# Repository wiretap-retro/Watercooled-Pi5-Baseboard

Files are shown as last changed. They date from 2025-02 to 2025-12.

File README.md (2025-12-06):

# Watercooled Pi5 Baseboard
A baseboard for setting up a watercooled Raspberry Pi 5.

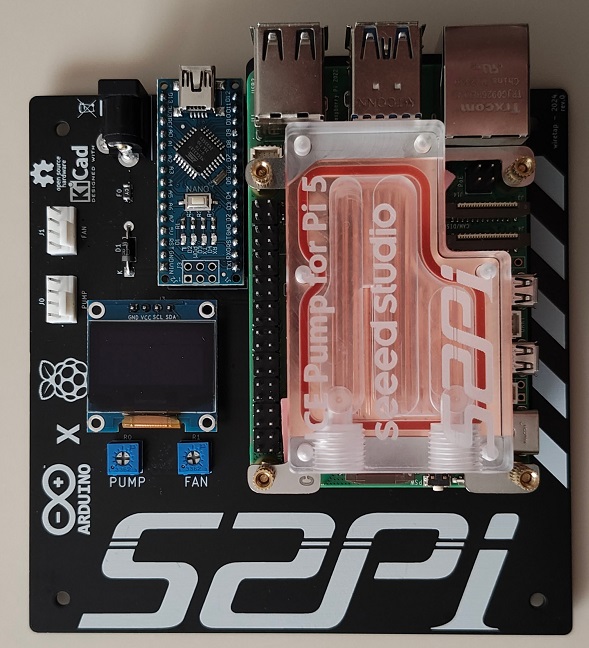
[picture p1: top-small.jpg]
board

\
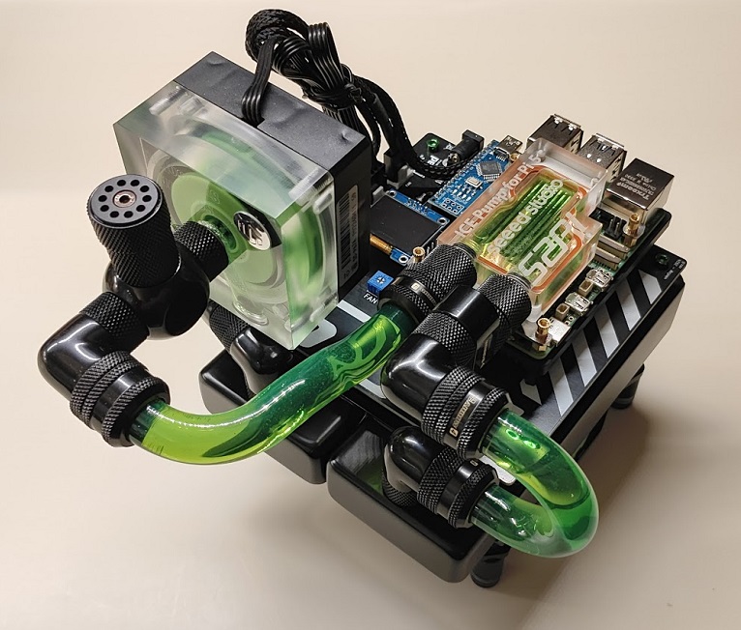
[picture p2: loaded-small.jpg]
board2

\
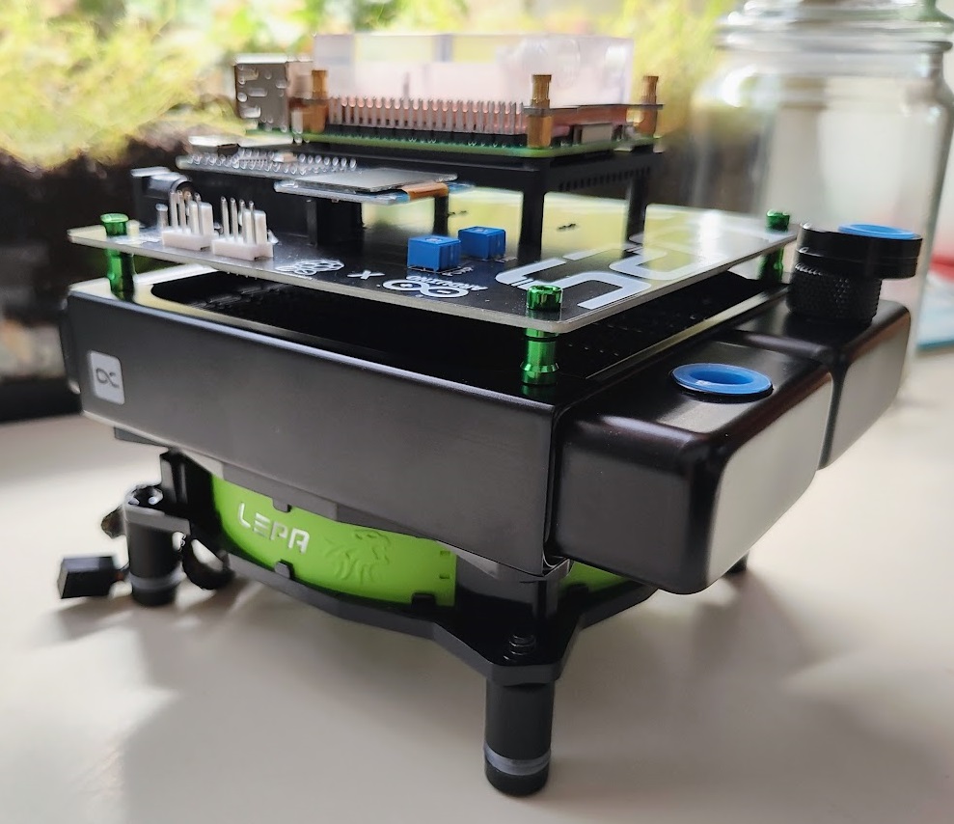
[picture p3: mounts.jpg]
mounts


## Info
In this repository you'll find my Watercooled Raspberry Pi 5 baseboard. It features mounts for the Raspberry Pi 2/3/4/5, an Arduino Nano, and a 120mm fan/radiator. The baseboard is powered through the 5.5x2.1mm 12V barrel jack, which powers the pump, fan, and Arduino. There is an onboard 4A fuse for protection. The Pi is powered separate with its own USB power input.\
\
The Arduino is used for the PWM fan and pump control so it leaves the entire Pi header available for hat use. \
\
Arduino Nano connections:\
A0: Pump Adjustment 10k trim pot input \
A1: Fan Adjustment 10k trim pot input \
A4: SDA for OLED screen (SSD1306 model) \
A5: SCL for OLED screen (SSD1306 model) \
D2: Pump tachometer input \
D6: Fan tachometer input \
D9: PWM pump demand output \
D10: PWM fan demand output
\
\
For the radiator and fan, you'll want to use some generic standoffs commonly found on Aliexpress, Amazon, or Ebay. These will all depend on your fan and radiator choices for what fits best. A M3 5mm standoff provides a sufficient gap between the board and radiator to allow airflow to pass through. After all, watercooling even a Raspberry Pi 5 is pointless and passive cooling alone is enough at the factory clockspeed. 

## Code
I have uploaded some sample code for you. When designing the board, I stupidly designed the tach pins where only one of the ports has an interrupt capability. This requires using the PinChangeInterrupts library. I have attached the settings file for you to overwrite the one that is automatically downloaded, then it will properly display the fan tachometer. This code is fully tested working for fan and pump control.
\
See picture below for the screen layout:
\
\
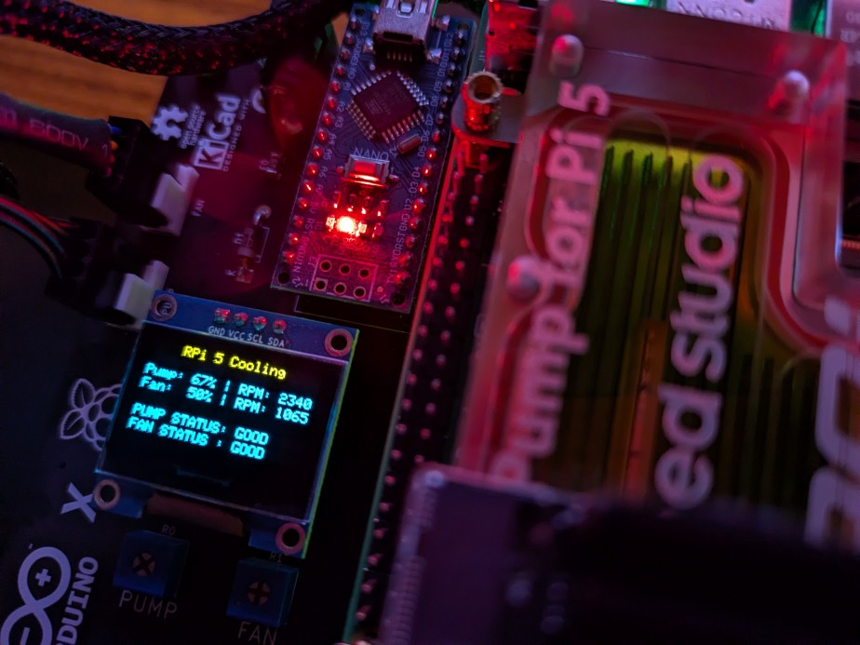
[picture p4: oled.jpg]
oled

## License
UNLICENSE -- do what you want with it.

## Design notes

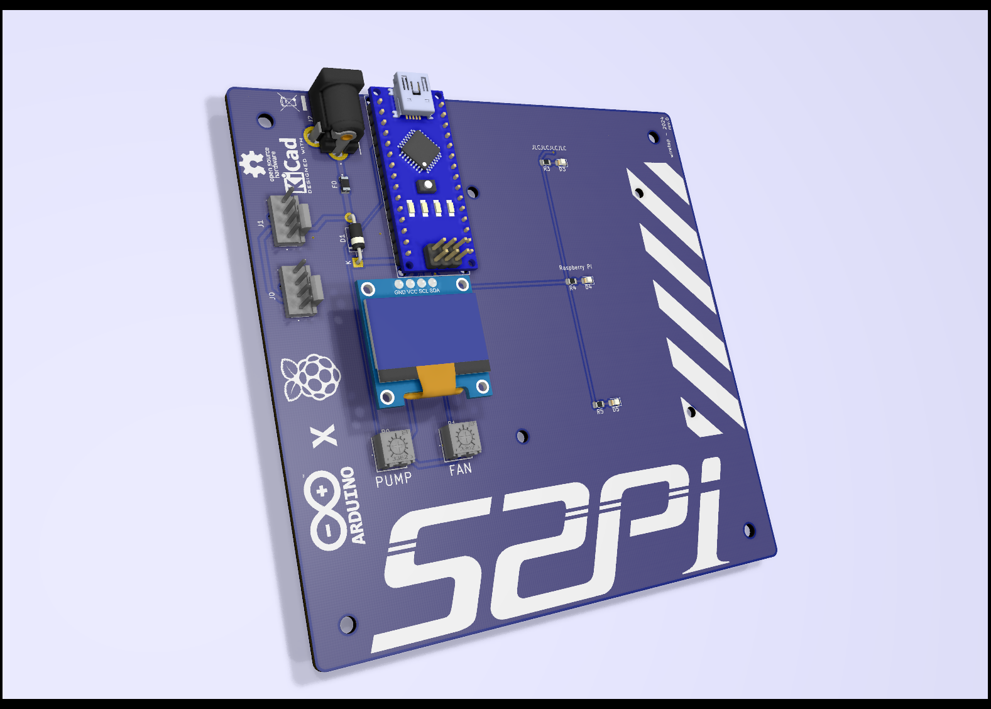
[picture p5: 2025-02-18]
Pi5-wc-board/watercooled-pi-120mm.png

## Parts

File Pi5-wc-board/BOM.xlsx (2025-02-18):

Reference | Quantity | Value | Footprint | Manufacturer | Part Number | Mouser Part Number | Notes
D1 | 1 | 1N4007 | Diode_THT:D_DO-41_SOD81_P10.16mm_Horizontal | Diotec Semiconductor | 1N4007 | 637-1N4007
D2 D3 D4 D5 D6 D7 D8 D9 D10 D11 D12 D13 | 12 | LED_Small | LED_SMD:LED_0805_2012Metric_Pad1.15x1.40mm_HandSolder |  |  |  | Any 0805 SMD LED
F0 | 1 | 1206L400_12SLWR | 1206L075SLYR | LITTELFUSE | 1206L400/12SLWR | 576-1206L400/12SLWR
J1 J0 | 2 | 47053-3000 | 470533000 | Molex | 47053-3000 | 538-47053-3000
J2 | 1 | 694106301002 | 694106301002_1 | Wurth Elektronik | 694106301002 | 710-694106301002
J3 | 1 | Conn_01x04 | Connector_PinSocket_2.54mm:PinSocket_1x04_P2.54mm_Vertical | Harwin | M20-7820446 | 855-M20-7820446
R1 R0 | 2 | 3362P-1-103 | 3362P_1 | Bourns | 3362P-1-103 | 652-3362P-1-103
R2 R3 R4 R5 R6 R7 R8 R9 R10 R11 R12 R13 | 12 | R_Small | Resistor_SMD:R_0805_2012Metric_Pad1.15x1.40mm_HandSolder |  |  |  | 0805 SMD resistor appropriate for your LEDs (i.e. 1k)
TB0 | 1 | ARDUINO_NANO | SamacSys_Parts:Arduino_Nano_Socket | Arduino | Nano |  | Arduino Nano header is optional -- can direct solder

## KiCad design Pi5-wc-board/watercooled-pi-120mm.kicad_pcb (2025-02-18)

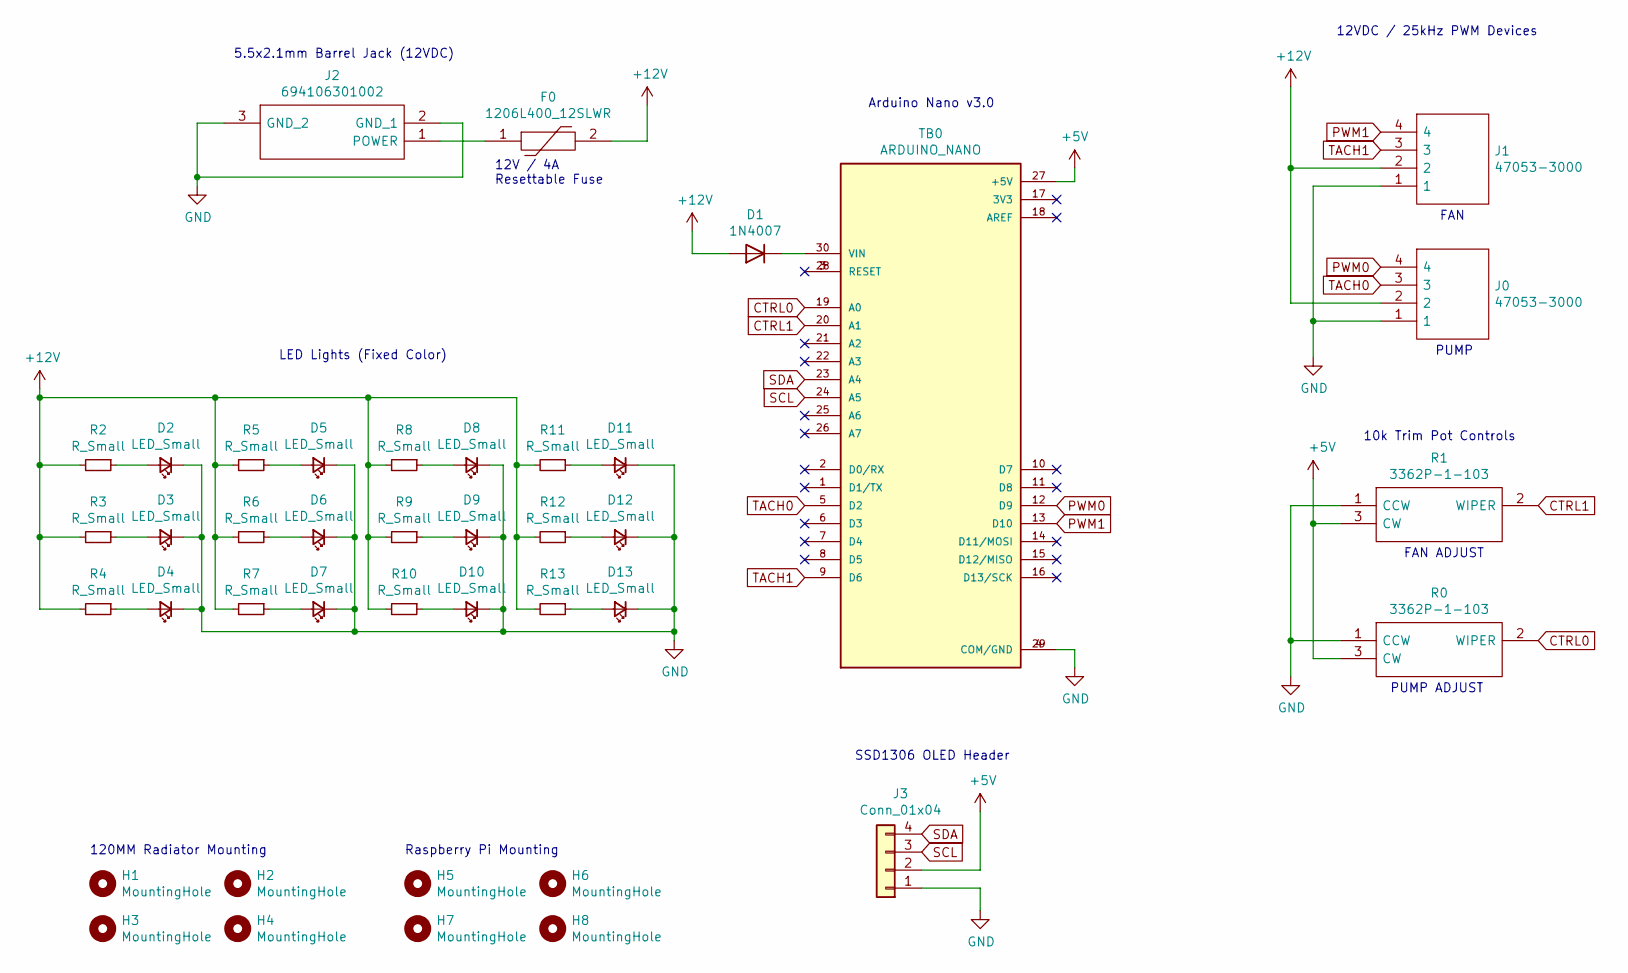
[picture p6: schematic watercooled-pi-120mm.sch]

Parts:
D1: 1N4007; D_DO-41_SOD81_P10.16mm_Horizontal
D2, D3, D4, D5, D6, D7, D8, D9, D10, D11, D12, D13: LED_Small; LED_0805_2012Metric_Pad1.15x1.40mm_HandSolder
F0: 1206L400_12SLWR; 1206L075SLYR; Mouser Part Number 576-1206L400/12SLWR
H1, H2, H3, H4: MountingHole; MountingHole_3.2mm_M3
H5, H6, H7, H8: MountingHole; MountingHole_2.7mm_M2.5
J0, J1: 47053-3000; 470533000; Mouser Part Number 538-47053-3000
J2: 694106301002; 694106301002_1; Mouser Part Number 710-694106301002
J3: Conn_01x04; PinSocket_1x04_P2.54mm_Vertical
R0, R1: 3362P-1-103; 3362P_1; Mouser Part Number 652-3362P-1-103
R2, R3, R4, R5, R6, R7, R8, R9, R10, R11, R12, R13: R_Small; R_0805_2012Metric_Pad1.15x1.40mm_HandSolder
TB0: ARDUINO_NANO; Arduino_Nano_Socket

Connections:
+5V: J3.2, R0.3 (CW), R1.3 (CW), TB0.27 (+5V)
+12V: D1.2 (A), F0.2, J0.2, J1.2, R2.2, R3.2, R4.2, R5.2, R6.2, R7.2, R8.2, R9.2, R10.2, R11.2, R12.2, R13.2
CTRL0: R0.2 (WIPER), TB0.19 (A0)
CTRL1: R1.2 (WIPER), TB0.20 (A1)
GND: D2.1 (K), D3.1 (K), D4.1 (K), D5.1 (K), D6.1 (K), D7.1 (K), D8.1 (K), D9.1 (K), D10.1 (K), D11.1 (K), D12.1 (K), D13.1 (K), J0.1, J1.1, J2.2 (GND_1), J2.3 (GND_2), J3.1, R0.1 (CCW), R1.1 (CCW), TB0.4 (COM/GND), TB0.29 (COM/GND)
unnamed: D1.1 (K), TB0.30 (VIN)
unnamed: D2.2 (A), R2.1
unnamed: D3.2 (A), R3.1
unnamed: D4.2 (A), R4.1
unnamed: D5.2 (A), R5.1
unnamed: D6.2 (A), R6.1
unnamed: D7.2 (A), R7.1
unnamed: D8.2 (A), R8.1
unnamed: D9.2 (A), R9.1
unnamed: D10.2 (A), R10.1
unnamed: D11.2 (A), R11.1
unnamed: D12.2 (A), R12.1
unnamed: D13.2 (A), R13.1
unnamed: F0.1, J2.1 (POWER)
unnamed: TB0.3 (RESET), TB0.28 (RESET)
PWM0: J0.4, TB0.12 (D9)
PWM1: J1.4, TB0.13 (D10)
SCL: J3.3, TB0.24 (A5)
SDA: J3.4, TB0.23 (A4)
TACH0: J0.3, TB0.5 (D2)
TACH1: J1.3, TB0.9 (D6)

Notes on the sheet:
FAN
PUMP
12VDC / 25kHz PWM Devices
Arduino Nano v3.0
FAN ADJUST
PUMP ADJUST
10k Trim Pot Controls
12V / 4A Resettable Fuse
5.5x2.1mm Barrel Jack (12VDC)
SSD1306 OLED Header
120MM Radiator Mounting
Raspberry Pi Mounting
LED Lights (Fixed Color)

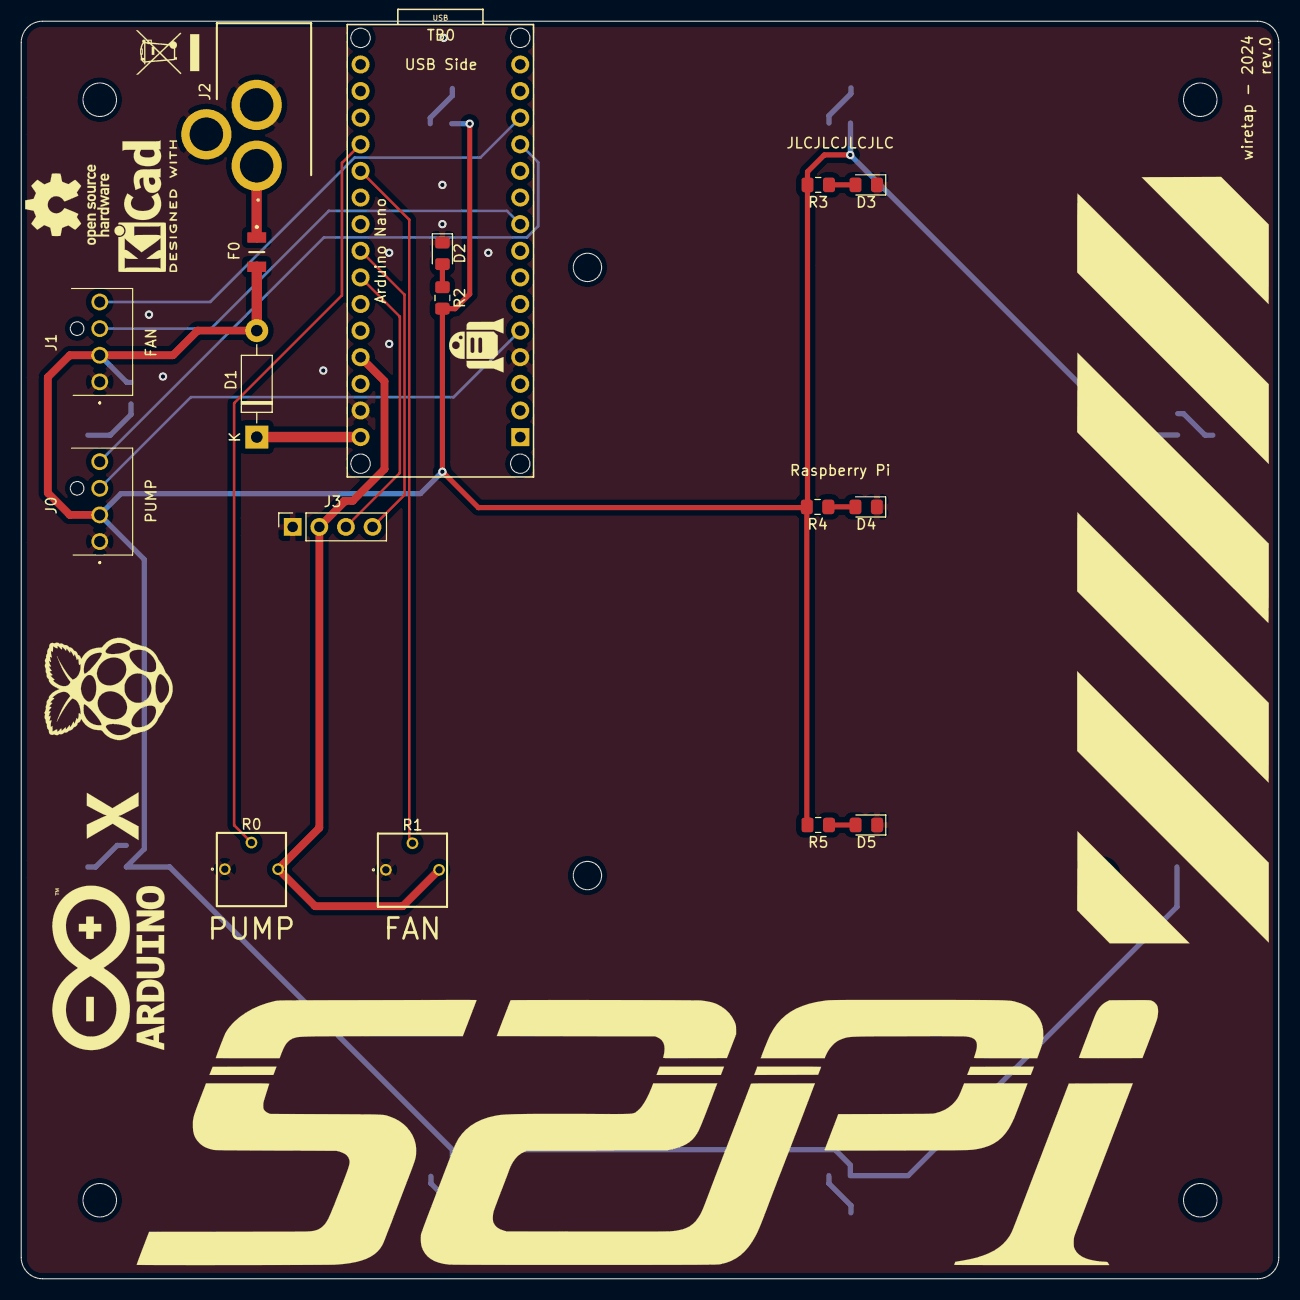
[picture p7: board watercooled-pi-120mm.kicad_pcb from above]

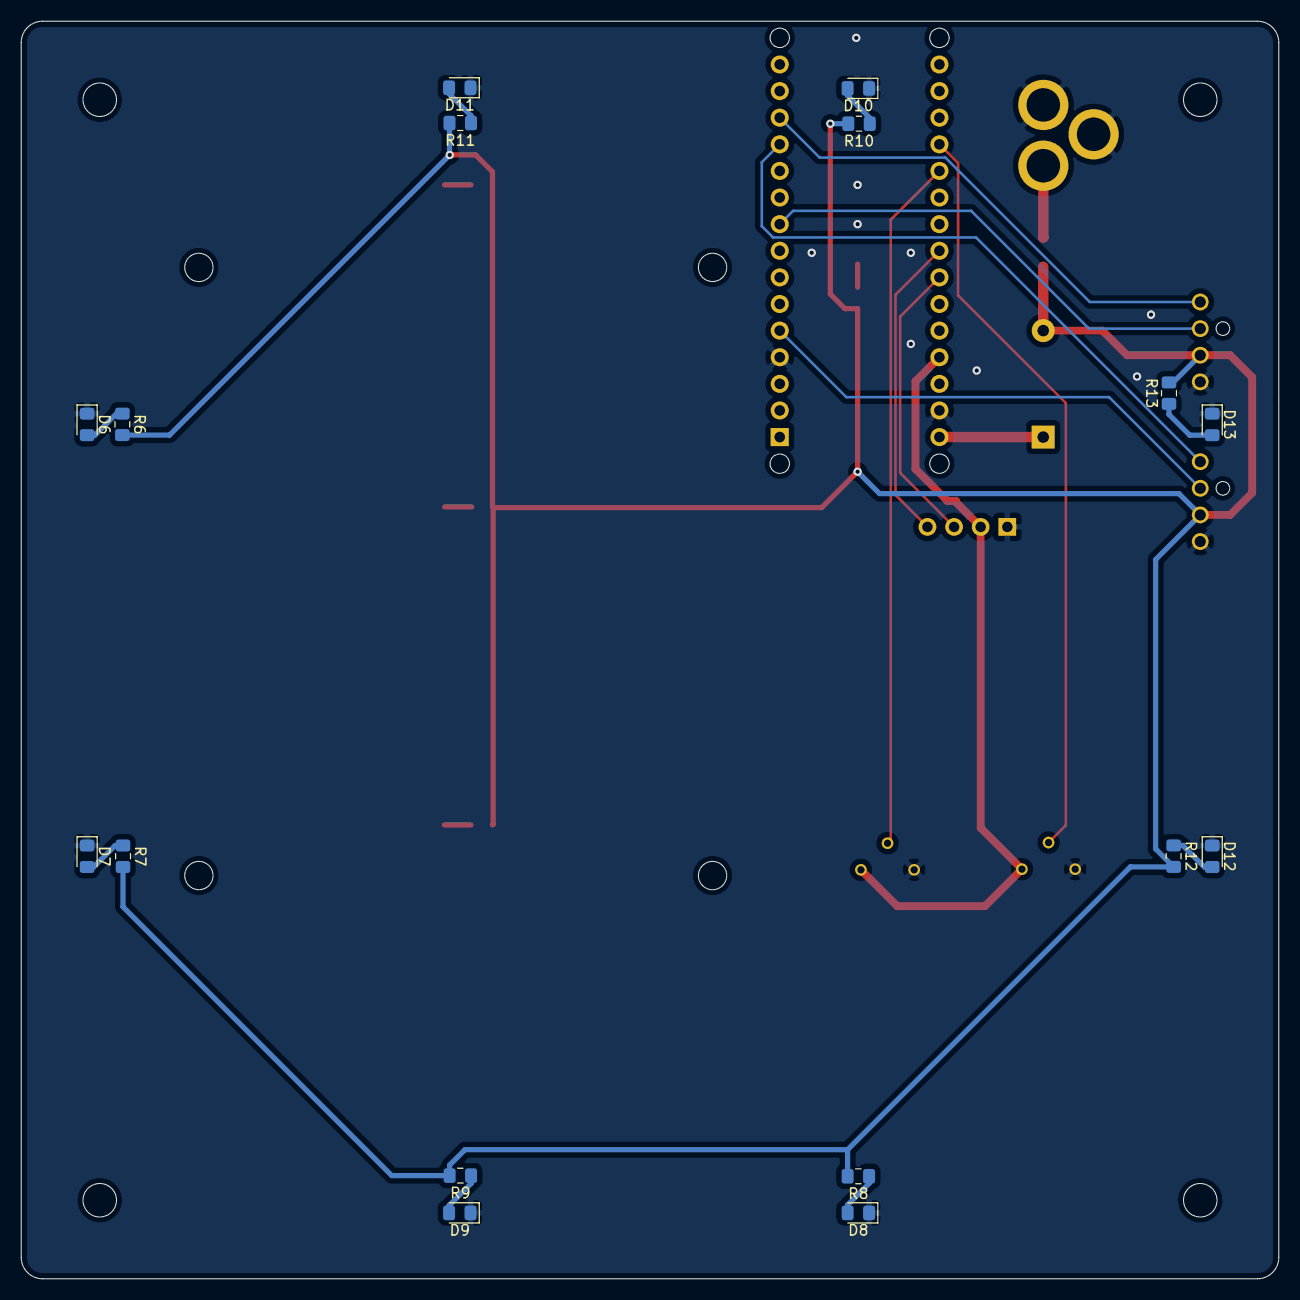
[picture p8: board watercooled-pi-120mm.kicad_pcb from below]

Board: 2 copper layers, 120.0 x 120.0 mm, 41 parts (16 on the bottom side), 26 nets.

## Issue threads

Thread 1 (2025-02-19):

0805 smd led

TheRealKingPin, 2025-02-19:
Random question, did you solder the 0805 smd leds to the top and bottom of the board? I'm assuming these are what are providing the green underglow in some of your images.

wiretap-retro, 2025-02-19:
Yes, those are just LEDs for the purpose of underglow between the board and radiator gap. They aren't required for functionality.

Closed 2025-02-19.

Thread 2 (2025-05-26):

G1/4 to g1/8 adapter

TheRealKingPin, 2025-05-26:
I know it's a long shot but do you happen to know the brand you used for the g1/4 to g1/8 adapter? I'm having a tough time finding one that fits the 52pi ice pump without hitting the bracket or the raspberry pi 5.

wiretap-retro, 2025-05-28:
These are what I'm using. https://www.performance-pcs.com/products/bitspower-premium-g1-8-matte-black-g1-8-to-ig1-4-adapter-bp-mbwp-c10

Closed 2025-05-28.

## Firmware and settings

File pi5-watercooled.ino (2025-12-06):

/*
  Wiretap's Watercooled Pi 5 Baseboard
  sample code for Arduino Nano PWM pump
  and fan control.
  https://github.com/wiretap-retro/Watercooled-Pi5-Baseboard

  Sample code based on the project:
  pwm-fan-temp-sense.ino
  DroneBot Workshop 2025
  https://dronebotworkshop.com
  
  Code modified to fit this project
  thanks to the excellent example
  from DroneBot Workshop.
*/

// Include required libraries
#include <Wire.h>
#include <Adafruit_GFX.h>
#include <Adafruit_SSD1306.h>
#include <PinChangeInterrupt.h>

const int PUMP_POT_PIN = A0;   // Pump potentiometer speed control
const int FAN_POT_PIN = A1;    // Fan potentiometer speed control
const int PUMP_TACH_PIN = 2;  // Pump tachometer speed reading D2
const int FAN_TACH_PIN = 6;   // Fan tachometer speed reading D6
const int PUMP_PWM_PIN = 9;   // Pump PWM demand signal D9
const int FAN_PWM_PIN = 10;   // Fan PWM demand signal D10

#define SCREEN_WIDTH 128
#define SCREEN_HEIGHT 64
#define OLED_RESET -1
Adafruit_SSD1306 display(SCREEN_WIDTH, SCREEN_HEIGHT, &Wire, OLED_RESET);

// PWM settings
const int PWM_FREQ = 25000;    // 25 kHz frequency for computer fans
const int PWM_RESOLUTION = 8;  // 8-bit resolution (0-255)

// Tachometer variables
volatile unsigned long tachPulseCountFan = 0;
volatile unsigned long tachPulseCountPump = 0;
unsigned long lastTachTimeFan = 0;
unsigned long lastTachTimePump = 0;
const unsigned long TACH_SAMPLE_TIME = 2000;  // Sample period in milliseconds
unsigned long currentRPMfan = 0;
unsigned long currentRPMpump = 0;

// System variables
int fanSpeedPercent = 0;
int pumpSpeedPercent = 0;
bool fanFailure = false;
bool pumpFailure = false;

// Interrupt service routines for tachometers
void tachISR1() {
  tachPulseCountFan = tachPulseCountFan + 1;
}

void tachISR2() {
  tachPulseCountPump = tachPulseCountPump + 1;
}

void setup() {

  // Start Serial Monitor
  Serial.begin(115200);
  Serial.println("Pump/Fan Control System Starting...");

  // Initialize I2C
  Wire.begin();  // SDA=4, SCL=5

  // Initialize OLED display
  if (!display.begin(SSD1306_SWITCHCAPVCC, 0x3C)) {
    Serial.println("SSD1306 allocation failed");
    for (;;)
      ;
  }
  display.clearDisplay();
  display.setTextSize(1);
  display.setTextColor(WHITE);
  display.setCursor(0, 0);
  display.println("Pump/Fan Controller");
  display.println("Initializing...");
  display.display();

  // Configure PWM
  analogWrite(FAN_PWM_PIN, PWM_FREQ);
  analogWrite(PUMP_PWM_PIN, PWM_FREQ);

  // Configure pins
  pinMode(FAN_TACH_PIN, INPUT_PULLUP);
  pinMode(PUMP_TACH_PIN, INPUT_PULLUP);

  // Setup tachometer interrupt
  attachPCINT(digitalPinToPCINT(FAN_TACH_PIN), tachISR1, FALLING);
  attachInterrupt(digitalPinToInterrupt(PUMP_TACH_PIN), tachISR2, FALLING);

  // Initialize timing
  lastTachTimeFan = millis();
  lastTachTimePump = millis();

  Serial.println("System ready!");

  delay(2000);  // Delay to show startup message
}

void loop() {

  // Calculate RPM every 2 seconds
  unsigned long currentTimeFan = millis();
  unsigned long currentTimePump = millis();

  // Check for manual override mode using potentiometer
  int potValueFan = analogRead(FAN_POT_PIN);
  int potValuePump = analogRead(PUMP_POT_PIN);

  // Convert pot value to percentage
  fanSpeedPercent = map(potValueFan, 0, 1024, 0, 100);
  pumpSpeedPercent = map(potValuePump, 0, 1024, 0, 100);

  // Convert percentage to PWM value
  int pwmValueFan = map(fanSpeedPercent, 0, 100, 0, 255);
  int pwmValuePump = map(pumpSpeedPercent, 0, 100, 0, 255);

  // Set PWM speed based on mapped value
  analogWrite(FAN_PWM_PIN, pwmValueFan);
  analogWrite(PUMP_PWM_PIN, pwmValuePump);

  if (currentTimeFan - lastTachTimeFan >= TACH_SAMPLE_TIME) {
    // Calculate RPM (2 pulses per revolution for most fans)
    currentRPMfan = (tachPulseCountFan * 60000) / (TACH_SAMPLE_TIME * 2);
	
    // Check for fan failure
    if (currentRPMfan < 100) {
      fanFailure = true;
    } else {
      fanFailure = false;
    }

    // Reset fan counters
    tachPulseCountFan = 0;
    lastTachTimeFan = currentTimeFan;
  }
  
  if (currentTimePump - lastTachTimePump >= TACH_SAMPLE_TIME) {
    // Calculate RPM (2 pulses per revolution for most pumps)
    currentRPMpump = (tachPulseCountPump * 60000) / (TACH_SAMPLE_TIME * 2);
	
	// Check for pump failure
    if (currentRPMpump < 100) {
      pumpFailure = true;
    } else {
      pumpFailure = false;
    }

  // Reset pump counters
	tachPulseCountPump = 0;
	lastTachTimePump = currentTimePump;
  }

  // Update OLED display
  updateDisplay();

  Serial.print("Pump Speed: ");
  Serial.print(pumpSpeedPercent);
  Serial.print("%  RPM: ");
  Serial.print(currentRPMpump);
  Serial.print(" | Fan Speed: ");
  Serial.print(fanSpeedPercent);
  Serial.print("%  RPM: ");
  Serial.print(currentRPMfan);
  if (pumpFailure) Serial.print(" | PUMP FAILURE!");
  if (fanFailure) Serial.print(" | FAN FAILURE!");
  Serial.println();

  delay(500);
}

void updateDisplay() {
  display.clearDisplay();

  // Title
  display.setTextSize(1);
  display.setCursor(0, 0);
  display.println("    RPi 5 Cooling");

  // Pump speed
  display.setCursor(0, 16);
  display.print("Pump: ");
  display.print(pumpSpeedPercent);
  display.print("%");
  display.print(" | RPM: ");
  display.print(currentRPMpump);
  display.println();

  // Fan speed
  display.setCursor(0, 26);
  display.print("Fan:  ");
  display.print(fanSpeedPercent);
  display.print("%");
  display.print(" | RPM: ");
  display.print(currentRPMfan);
  display.println();
  
  // Status indicators
  display.setCursor(0, 46);
  if (pumpFailure) {
    display.println("PUMP STATUS: FAILURE!");
	}
  else {
    display.println("PUMP STATUS: GOOD");
  }

    display.setCursor(0, 56);
  if (fanFailure) {
    display.println("FAN STATUS : FAILURE!");
	}
  else {
    display.println("FAN STATUS : GOOD");
  }

  display.display();
}

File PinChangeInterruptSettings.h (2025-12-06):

/*
Copyright (c) 2014-2015 NicoHood
See the readme for credit to other people.

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
THE SOFTWARE IS PROVIDED "AS IS", WITHOUT WARRANTY OF ANY KIND, EXPRESS OR
IMPLIED, INCLUDING BUT NOT LIMITED TO THE WARRANTIES OF MERCHANTABILITY,
FITNESS FOR A PARTICULAR PURPOSE AND NONINFRINGEMENT. IN NO EVENT SHALL THE
AUTHORS OR COPYRIGHT HOLDERS BE LIABLE FOR ANY CLAIM, DAMAGES OR OTHER
LIABILITY, WHETHER IN AN ACTION OF CONTRACT, TORT OR OTHERWISE, ARISING FROM,
OUT OF OR IN CONNECTION WITH THE SOFTWARE OR THE USE OR OTHER DEALINGS IN
THE SOFTWARE.
*/

// include guard
#pragma once

//================================================================================
// General Settings
//================================================================================

/* Settings to de/activate ports/pins
This will save you flash and ram because the arrays
are managed dynamically with the definitions below.
Make sure you still have all needed ports activated.
Each deactivated port saves 3 bytes of ram.
If you deactivate the whole port,
you dont need to deactivate the pins.
Same for the port if you deactivate all 8 pins.
You dont have to deactivate pins/ports that dont exist.
That is done by the macros. */

#ifndef PCINT_ENABLE_MANUAL

// #define PCINT_ENABLE_PORT0
// #define PCINT_ENABLE_PORT1
#define PCINT_ENABLE_PORT2
// #define PCINT_ENABLE_PORT3

// #define PCINT_ENABLE_PCINT0
// #define PCINT_ENABLE_PCINT1
// #define PCINT_ENABLE_PCINT2
// #define PCINT_ENABLE_PCINT3
// #define PCINT_ENABLE_PCINT4
// #define PCINT_ENABLE_PCINT5
// #define PCINT_ENABLE_PCINT6
// #define PCINT_ENABLE_PCINT7
// #define PCINT_ENABLE_PCINT8
// #define PCINT_ENABLE_PCINT9
// #define PCINT_ENABLE_PCINT10
// #define PCINT_ENABLE_PCINT11
// #define PCINT_ENABLE_PCINT12
// #define PCINT_ENABLE_PCINT13
// #define PCINT_ENABLE_PCINT14
// #define PCINT_ENABLE_PCINT15
// #define PCINT_ENABLE_PCINT16
// #define PCINT_ENABLE_PCINT17
#define PCINT_ENABLE_PCINT18
#define PCINT_ENABLE_PCINT19
#define PCINT_ENABLE_PCINT20
#define PCINT_ENABLE_PCINT21
#define PCINT_ENABLE_PCINT22
#define PCINT_ENABLE_PCINT23
#define PCINT_ENABLE_PCINT24
#define PCINT_ENABLE_PCINT25
#define PCINT_ENABLE_PCINT26
#define PCINT_ENABLE_PCINT27
#define PCINT_ENABLE_PCINT28
#define PCINT_ENABLE_PCINT29
#define PCINT_ENABLE_PCINT30
#define PCINT_ENABLE_PCINT31

#endif

#ifdef ARDUINO
// use API with function pointers (better optimized with .a linkage)
#define PCINT_API

// is the library compiled via .a file?
// see readme for more information
#define PCINT_ALINKAGE

// force compile all enabled port ISRs (with .a linkage)
//#define PCINT_COMPILE_ENABLED_ISR

#endif

//================================================================================
// Suggested Settings
//================================================================================

// Arduino Uno (328)
#if defined(__AVR_ATmega328__) || defined(__AVR_ATmega328P__) || defined(__AVR_ATmega168__) || defined(__AVR_ATmega88__)
/* Reordering interrupt callbacks priority
Port0 has SPI on higher pins, ordering is fine
Port1 has I2C on higher pins, ordering is fine
Port2 has USART and Pin Interrupt on lower pins,
move the priority down
Its more likely the user will use pin 4-7
*/
#if !defined(PCINT_CALLBACK_PORT2)
#define PCINT_CALLBACK_PORT2 \
PCINT_CALLBACK(4, 20); \
PCINT_CALLBACK(5, 21); \
PCINT_CALLBACK(6, 22); \
PCINT_CALLBACK(7, 23); \
PCINT_CALLBACK(0, 16); /* USART RX */ \
PCINT_CALLBACK(1, 17); /* USART TX */ \
PCINT_CALLBACK(2, 18); /* Pin Interrupt 0 */ \
PCINT_CALLBACK(3, 19); /* Pin Interrupt 1 */
#endif

// deactivate crystal and reset pins by default
#if defined(PCINT_ENABLE_PCINT6)
#undef PCINT_ENABLE_PCINT6 // crystal
#endif
#if defined(PCINT_ENABLE_PCINT7)
#undef PCINT_ENABLE_PCINT7 // crystal
#endif
#if defined(PCINT_ENABLE_PCINT14)
#undef PCINT_ENABLE_PCINT14 // reset
#endif
#endif

// Arduino Mega (2560)
#if defined(ARDUINO_AVR_MEGA2560) || defined(ARDUINO_AVR_MEGA)
/* Port1 is structured a bit more complicated
Also only 3 pins are connected on standard boards
Seeeduino Mega has these pins optional!
Disabling Port1 gives more speed and uses less flash
Pins: 0(RX0), 14(TX3), 15(RX3) */
#if defined(PCINT_ENABLE_PORT1)
#undef PCINT_ENABLE_PORT1 // better performence
#endif

/* Reordering interrupt callbacks priority
Port2 has SPI on lower pins, move the priority down
Its more likely the user will use pin 10-13
Port1 by default deactivated, ordering is fine
Port2 only has ADCs, ordering is fine
*/
#if !defined(PCINT_CALLBACK_PORT0)
#define PCINT_CALLBACK_PORT0 \
PCINT_CALLBACK(4, 4); \
PCINT_CALLBACK(5, 5); \
PCINT_CALLBACK(6, 6); \
PCINT_CALLBACK(7, 7); \
PCINT_CALLBACK(0, 0); /* SPI SS */ \
PCINT_CALLBACK(1, 1); /* SPI SCK */ \
PCINT_CALLBACK(2, 2); /* SPI MISO */ \
PCINT_CALLBACK(3, 3); /* SPI MOSI */
#endif
#endif
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
